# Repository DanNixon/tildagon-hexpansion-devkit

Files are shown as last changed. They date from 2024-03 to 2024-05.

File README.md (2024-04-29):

# Tildagon Hexpansion dev kit

A basic, quick and dirty development kit for hexpansions for the [Tildagon](https://tildagon.badge.emfcamp.org/) badge.

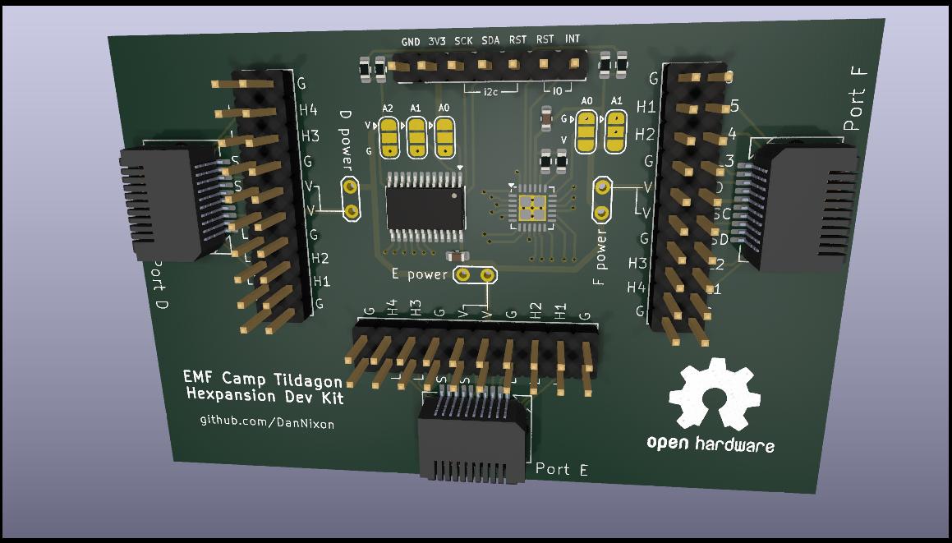
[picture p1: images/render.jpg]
KiCad render of dev kit PCB Dev kit PCB render


Accurately replicates i2c and low speed IO/LED drivers of ports D, E and F from the actual badge, with breakouts for the entire expansion port.
i2c is as per the actual badge, with the AW9523B connected to port 7 of the TCA9548A.
Default address configuration of both the AW9523B and TCA9548A match what is used on the badge (so you should not have to adjust the solder jumpers).

Paired with your ESP32-S3 dev board of choice, this should allow you to develop something more than "shape with LED" hexpansions prior to EMF 2024.

## Pinouts

"Pin" refers to the index used on the Tildagon design files.
"Letter" refers to the letter assigned to the pins in the Hexpansion example.
Why the two different pin identification schemes exist is a mystery to me...

### Low Speed

| Pin | Letter | Port D | Port E | Port F |
|-----|---|---|---|---|
| 1 | A | 1.0 | 0.2 | 0.7 |
| 2 | B | 1.1 | 0.3 | 1.4 |
| 3 | C | 1.2 | 0.4 | 1.5 |
| 4 | D | 1.3 | 0.5 | 1.6 |
| 5 | E | 0.0 | 0.6 | 1.7 |

### High Speed

| Pin | Letter |
|-----|---|
| 1 | F |
| 2 | G |
| 3 | H |
| 4 | I |

### i2c

| Bus | Port |
|-----|---|
| 4 | D |
| 5 | E |
| 6 | F |
| 7 | sys  |

## See also

- [badge-2024-hardware](https://github.com/emfcamp/badge-2024-hardware)
- [TCA9548A datasheet](https://www.ti.com/lit/ds/symlink/tca9548a.pdf)
- [AW9523B datasheet](https://cdn-shop.adafruit.com/product-files/4886/AW9523+English+Datasheet.pdf)
- [Hexpansion developer guide](https://tildagon.badge.emfcamp.org/technical-reference/hexpansions/)

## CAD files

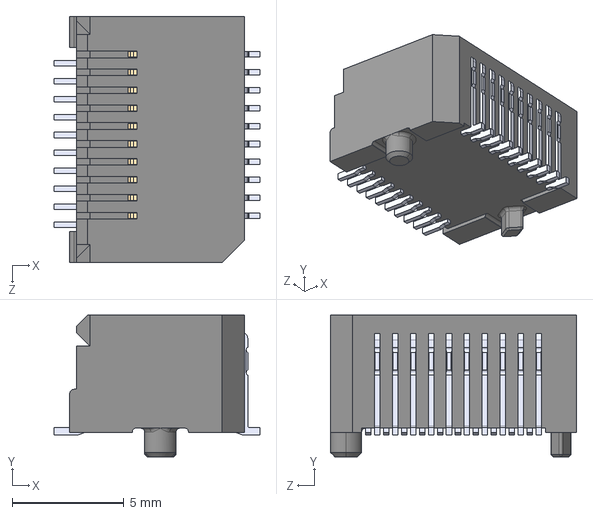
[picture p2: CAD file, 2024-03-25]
pcb/3d/UE75-A20-6000T.step
9.20 x 6.33 x 11.0 mm

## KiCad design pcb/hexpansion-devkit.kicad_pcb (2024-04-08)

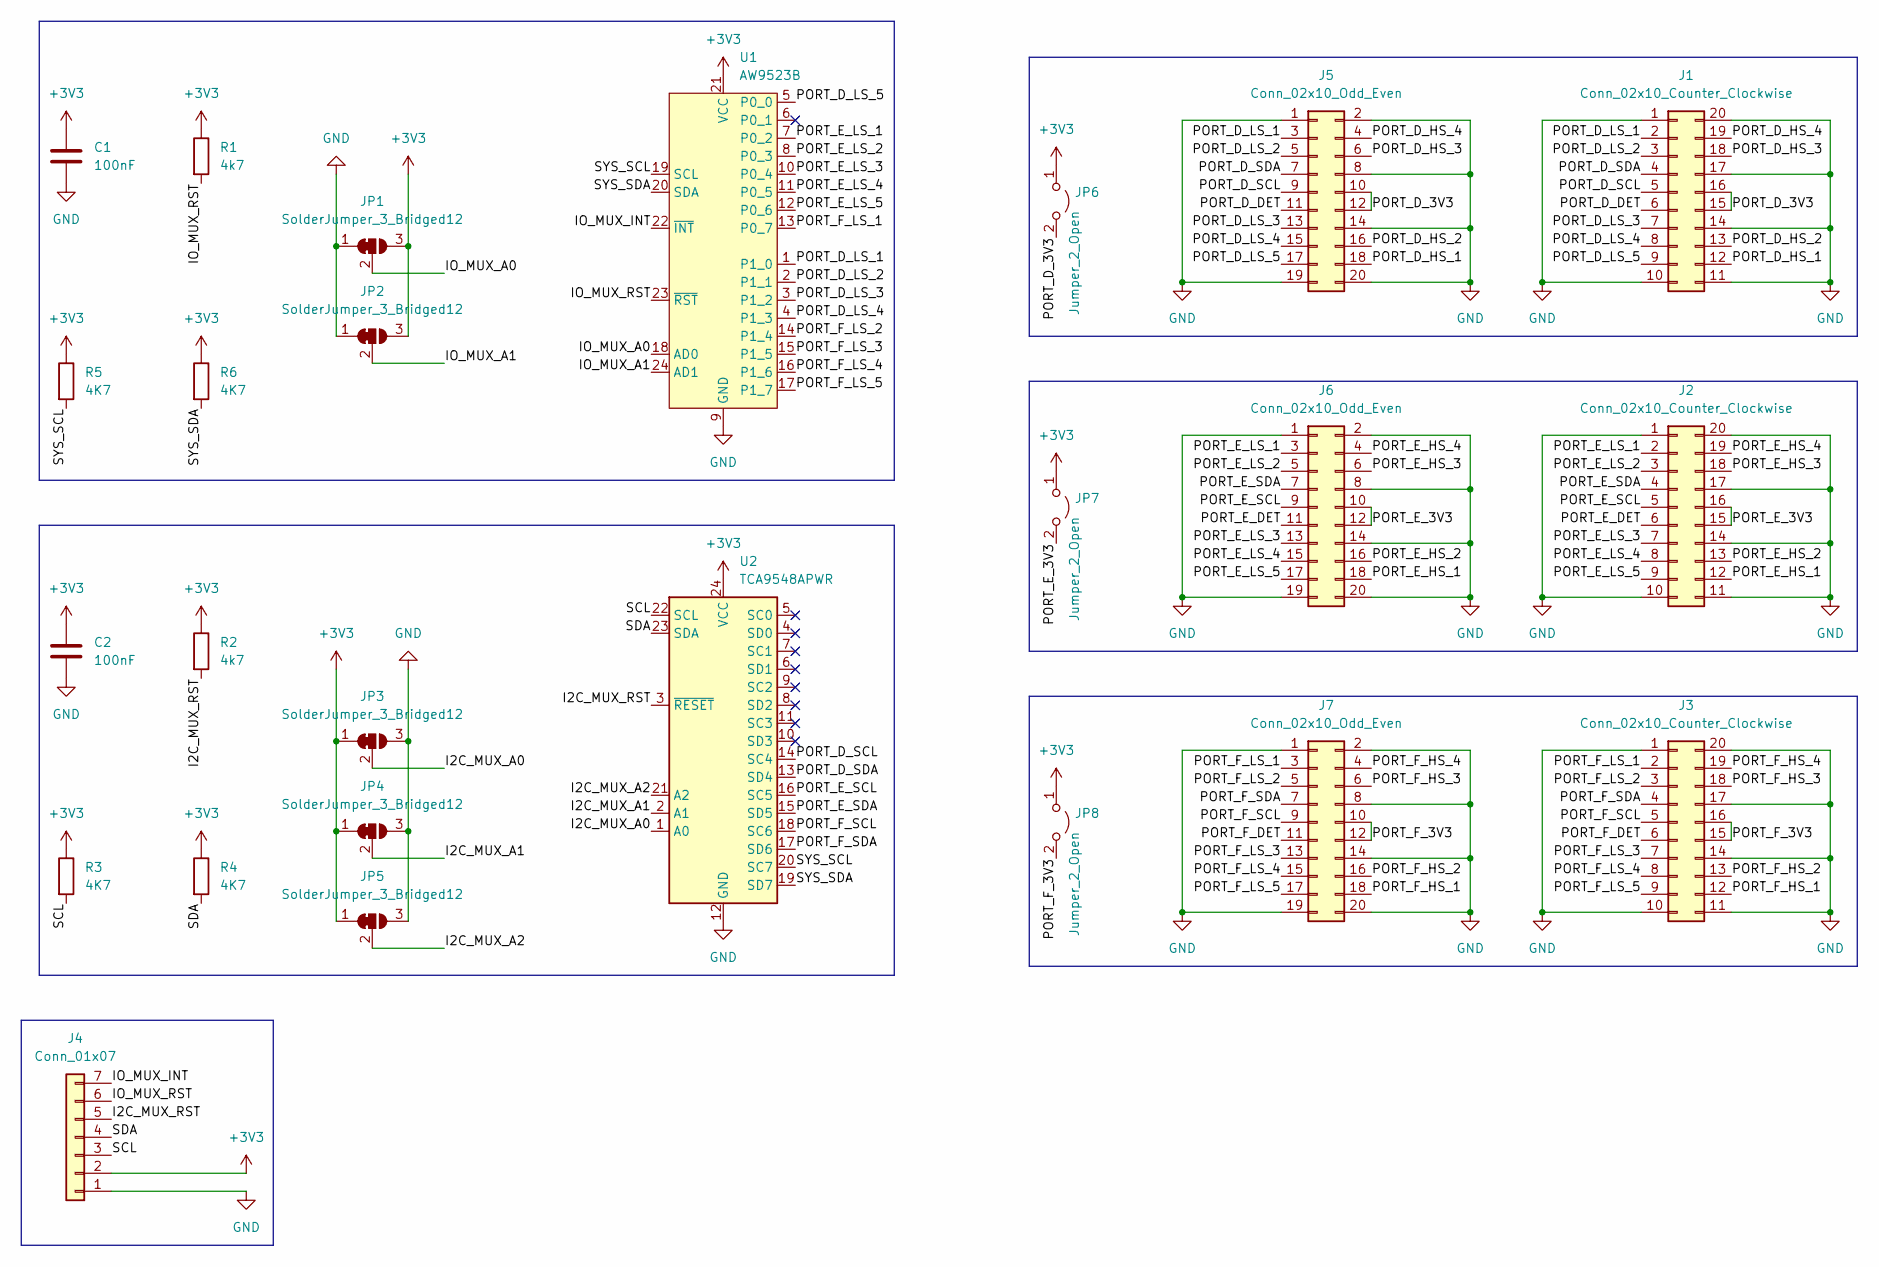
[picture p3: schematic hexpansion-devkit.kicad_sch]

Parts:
C1, C2: 100nF; C_0603_1608Metric; LCSC C497032
J1, J2, J3: Conn_02x10_Counter_Clockwise; SFP; LCSC C2897291
J4: Conn_01x07; PinHeader_1x07_P2.54mm_Vertical
J5, J6, J7: Conn_02x10_Odd_Even; PinHeader_2x10_P2.54mm_Vertical
JP1, JP2, JP3, JP4, JP5: SolderJumper_3_Bridged12; SolderJumper-3_P1.3mm_Bridged12_RoundedPad1.0x1.5mm
JP6, JP7, JP8: Jumper_2_Open; TestPoint_2Pads_Pitch2.54mm_Drill0.8mm
R1, R2: 4k7; R_0603_1608Metric; LCSC C217361
R3, R4, R5, R6: 4K7; R_0603_1608Metric; LCSC C217361
U1: AW9523B; QFN-24-1EP_4x4mm_P0.5mm_EP2.7x2.6mm; LCSC C148077
U2: TCA9548APWR; TSSOP-24_4.4x7.8mm_P0.65mm; LCSC C130026

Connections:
+3V3: C1.1, C2.1, J4.2, JP1.3 (B), JP2.3 (B), JP3.1 (A), JP4.1 (A), JP5.1 (A), JP6.1 (A), JP7.1 (A), JP8.1 (A), R1.1, R2.1, R3.1, R4.1, R5.1, R6.1, U1.21 (VCC), U2.24 (VCC)
/I2C_MUX_A0: JP3.2 (C), U2.1 (A0)
/I2C_MUX_A1: JP4.2 (C), U2.2 (A1)
/I2C_MUX_A2: JP5.2 (C), U2.21 (A2)
/I2C_MUX_RST: J4.5, R2.2, U2.3 (~RESET)
/IO_MUX_A0: JP1.2 (C), U1.18 (AD0)
/IO_MUX_A1: JP2.2 (C), U1.24 (AD1)
/IO_MUX_INT: J4.7, U1.22 (~INT)
/IO_MUX_RST: J4.6, R1.2, U1.23 (~RST)
/PORT_D_3V3: J1.15, J1.16, J5.10, J5.12, JP6.2 (B)
/PORT_D_DET: J1.6, J5.11
/PORT_D_HS_1: J1.12, J5.18
/PORT_D_HS_2: J1.13, J5.16
/PORT_D_HS_3: J1.18, J5.6
/PORT_D_HS_4: J1.19, J5.4
/PORT_D_LS_1: J1.2, J5.3, U1.1 (P1_0)
/PORT_D_LS_2: J1.3, J5.5, U1.2 (P1_1)
/PORT_D_LS_3: J1.7, J5.13, U1.3 (P1_2)
/PORT_D_LS_4: J1.8, J5.15, U1.4 (P1_3)
/PORT_D_LS_5: J1.9, J5.17, U1.5 (P0_0)
/PORT_D_SCL: J1.5, J5.9, U2.14 (SC4)
/PORT_D_SDA: J1.4, J5.7, U2.13 (SD4)
/PORT_E_3V3: J2.15, J2.16, J6.10, J6.12, JP7.2 (B)
/PORT_E_DET: J2.6, J6.11
/PORT_E_HS_1: J2.12, J6.18
/PORT_E_HS_2: J2.13, J6.16
/PORT_E_HS_3: J2.18, J6.6
/PORT_E_HS_4: J2.19, J6.4
/PORT_E_LS_1: J2.2, J6.3, U1.7 (P0_2)
/PORT_E_LS_2: J2.3, J6.5, U1.8 (P0_3)
/PORT_E_LS_3: J2.7, J6.13, U1.10 (P0_4)
/PORT_E_LS_4: J2.8, J6.15, U1.11 (P0_5)
/PORT_E_LS_5: J2.9, J6.17, U1.12 (P0_6)
/PORT_E_SCL: J2.5, J6.9, U2.16 (SC5)
/PORT_E_SDA: J2.4, J6.7, U2.15 (SD5)
/PORT_F_3V3: J3.15, J3.16, J7.10, J7.12, JP8.2 (B)
/PORT_F_DET: J3.6, J7.11
/PORT_F_HS_1: J3.12, J7.18
/PORT_F_HS_2: J3.13, J7.16
/PORT_F_HS_3: J3.18, J7.6
/PORT_F_HS_4: J3.19, J7.4
/PORT_F_LS_1: J3.2, J7.3, U1.13 (P0_7)
/PORT_F_LS_2: J3.3, J7.5, U1.14 (P1_4)
/PORT_F_LS_3: J3.7, J7.13, U1.15 (P1_5)
/PORT_F_LS_4: J3.8, J7.15, U1.16 (P1_6)
/PORT_F_LS_5: J3.9, J7.17, U1.17 (P1_7)
/PORT_F_SCL: J3.5, J7.9, U2.18 (SC6)
/PORT_F_SDA: J3.4, J7.7, U2.17 (SD6)
/SCL: J4.3, R3.2, U2.22 (SCL)
/SDA: J4.4, R4.2, U2.23 (SDA)
/SYS_SCL: R5.2, U1.19 (SCL), U2.20 (SC7)
/SYS_SDA: R6.2, U1.20 (SDA), U2.19 (SD7)
GND: C1.2, C2.2, J1.1, J1.10, J1.11, J1.14, J1.17, J1.20, J2.1, J2.10, J2.11, J2.14, J2.17, J2.20, J3.1, J3.10, J3.11, J3.14, J3.17, J3.20, J4.1, J5.1, J5.2, J5.8, J5.14, J5.19, J5.20, J6.1, J6.2, J6.8, J6.14, J6.19, J6.20, J7.1, J7.2, J7.8, J7.14, J7.19, J7.20, JP1.1 (A), JP2.1 (A), JP3.3 (B), JP4.3 (B), JP5.3 (B), U1.9 (GND), U1.25 (GND), U2.12 (GND)

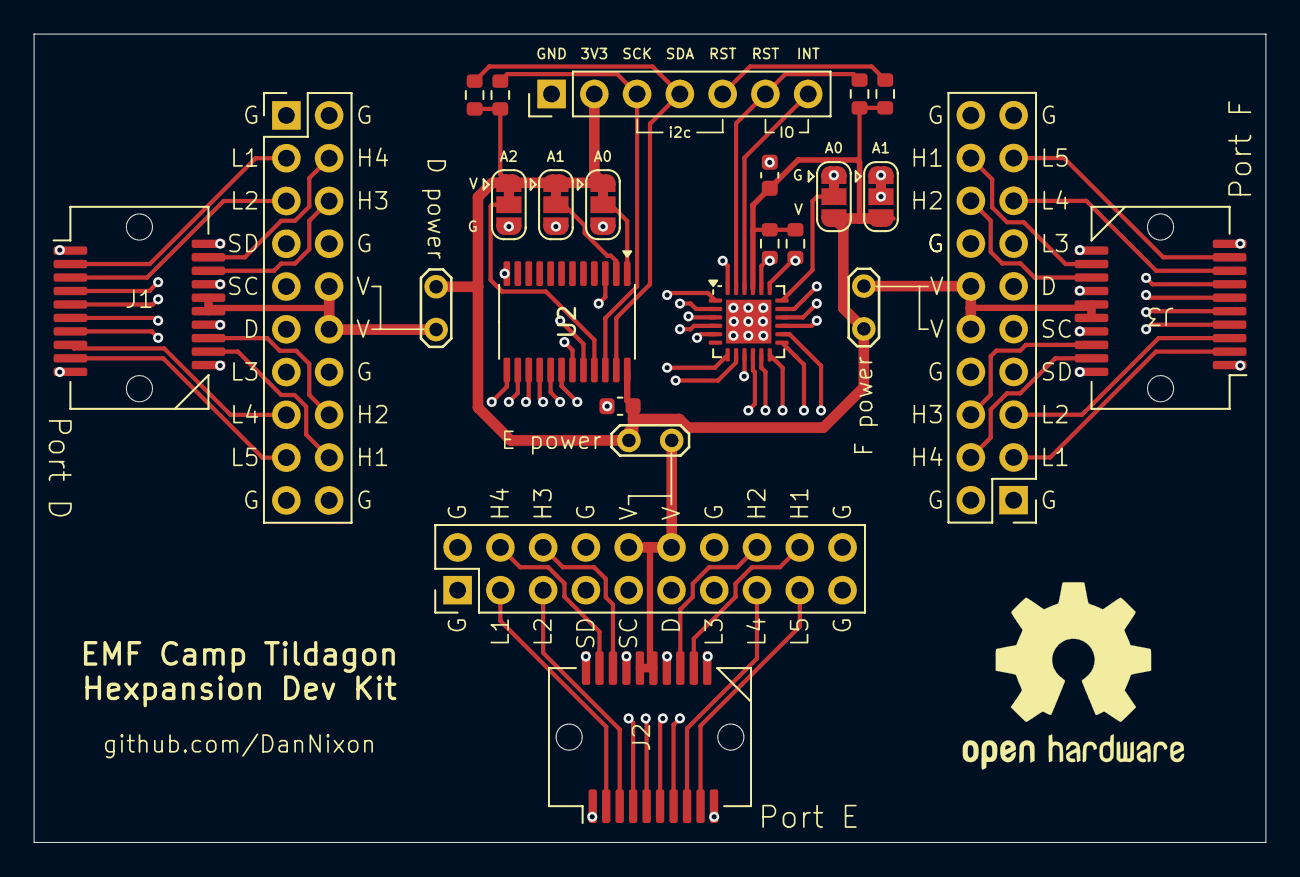
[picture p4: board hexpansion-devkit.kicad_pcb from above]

Board: 4 copper layers, 73.2 x 48.0 mm, 25 parts (0 on the bottom side), 53 nets.

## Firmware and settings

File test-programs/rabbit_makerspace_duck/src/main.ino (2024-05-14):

#include "Wire.h"
#include <Adafruit_AW9523.h>

static constexpr auto TCAADDR = 0x77;

void tcaselect(uint8_t i) {
  if (i > 7)
    return;

  Wire.beginTransmission(TCAADDR);
  Wire.write(1 << i);
  Wire.endTransmission();
}

void select_sys_i2c() { tcaselect(7); }

void select_port_d_i2c() { tcaselect(4); }

void select_port_e_i2c() { tcaselect(5); }

void select_port_f_i2c() { tcaselect(6); }

Adafruit_AW9523 badge_io;

Adafruit_AW9523 ms_hexpansion_io_1;
Adafruit_AW9523 ms_hexpansion_io_2;

uint8_t rabbit_red_pin = 0;    // Port D, LS E
uint8_t rabbit_green_pin = 10; // Port D, LS C
uint8_t rabbit_blue_pin = 11;  // Port D, LS D

uint8_t duck_red_pin = 15;   // Port F, LS E
uint8_t duck_green_pin = 14; // Port F, LS D
uint8_t duck_blue_pin = 13;  // Port F, LS C

void setup() {
  Serial.begin(115200);
  Serial.println("Adafruit AW9523 GPIO Expander test!");

  Wire.setPins(26, 27);
  Wire.begin();

  select_sys_i2c();

  Serial.print("Badge AW9523 good? : ");
  Serial.println(badge_io.begin(0x58));

  badge_io.pinMode(rabbit_red_pin, AW9523_LED_MODE);
  badge_io.pinMode(rabbit_green_pin, AW9523_LED_MODE);
  badge_io.pinMode(rabbit_blue_pin, AW9523_LED_MODE);

  badge_io.pinMode(duck_red_pin, AW9523_LED_MODE);
  badge_io.pinMode(duck_green_pin, AW9523_LED_MODE);
  badge_io.pinMode(duck_blue_pin, AW9523_LED_MODE);

  select_port_e_i2c();

  Serial.print("MS Hexpansion AW9523 1 good? : ");
  Serial.println(ms_hexpansion_io_1.begin(0x5A));

  Serial.print("MS Hexpansion AW9523 2 good? : ");
  Serial.println(ms_hexpansion_io_2.begin(0x5B));

  for (int i = 0; i < 16; i++) {
    ms_hexpansion_io_1.pinMode(i, AW9523_LED_MODE);
    ms_hexpansion_io_2.pinMode(i, AW9523_LED_MODE);
  }

  select_sys_i2c();

  badge_io.analogWrite(rabbit_red_pin, 4);
  badge_io.analogWrite(duck_blue_pin, 4);

  select_port_e_i2c();
}

void loop() {
  set_m_intensity(0);
  m_breathe_effect();

  set_m_intensity(0);
  m_scroll_effect();
}

// clang-format off
std::array<std::tuple<int, int>, 29> segments = {
    std::make_tuple(0, 7),
    std::make_tuple(0, 12),
    std::make_tuple(0, 13),
    std::make_tuple(0, 14),
    std::make_tuple(0, 15),
    std::make_tuple(0, 6),
    std::make_tuple(0, 5),
    std::make_tuple(0, 4),
    std::make_tuple(0, 3),
    std::make_tuple(0, 2),
    std::make_tuple(0, 1),
    std::make_tuple(0, 0),
    std::make_tuple(0, 11),
    std::make_tuple(0, 10),
    std::make_tuple(0, 9),
    std::make_tuple(0, 8),
    std::make_tuple(1, 7),
    std::make_tuple(1, 12),
    std::make_tuple(1, 6),
    std::make_tuple(1, 5),
    std::make_tuple(1, 4),
    std::make_tuple(1, 3),
    std::make_tuple(1, 2),
    std::make_tuple(1, 1),
    std::make_tuple(1, 0),
    std::make_tuple(1, 8),
    std::make_tuple(1, 9),
    std::make_tuple(1, 10),
    std::make_tuple(1, 11),
};
// clang-format on

void m_scroll_effect() {
  for (const auto &segment : segments) {
    auto expander = std::get<0>(segment);
    auto pin = std::get<1>(segment);

    set_m_intensity(0);
    if (expander == 0) {
      ms_hexpansion_io_1.analogWrite(pin, 12);
    } else if (expander == 1) {
      ms_hexpansion_io_2.analogWrite(pin, 12);
    }

    Serial.println("-");
    delay(50);
  }
}

void m_breathe_effect() {
  for (int i = 0; i < 24; i++) {
    set_m_intensity(i);
    delay(10);
  }
  for (int i = 22; i > 0; i--) {
    set_m_intensity(i);
    delay(10);
  }
}

void set_m_intensity(int intensity) {
  for (int i = 0; i < 16; i++) {
    ms_hexpansion_io_1.analogWrite(i, intensity);
    ms_hexpansion_io_2.analogWrite(i, intensity);
  }
}

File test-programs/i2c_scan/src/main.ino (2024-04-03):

#include "Wire.h"

static constexpr auto TCAADDR = 0x77;

void tcaselect(uint8_t i) {
  if (i > 7)
    return;

  Wire.beginTransmission(TCAADDR);
  Wire.write(1 << i);
  Wire.endTransmission();
}

void setup() {
  Serial.begin(115200);
  Serial.println("\nTCAScanner ready!");

  Wire.setPins(26, 27);
  Wire.begin();

  for (uint8_t t = 0; t < 8; t++) {
    tcaselect(t);
    Serial.print("TCA Port #");
    Serial.println(t);

    for (uint8_t addr = 0; addr <= 127; addr++) {
      if (addr == TCAADDR)
        continue;

      Wire.beginTransmission(addr);
      if (!Wire.endTransmission()) {
        Serial.print("Found I2C 0x");
        Serial.println(addr, HEX);
      }
    }
  }

  Serial.println("\ndone");
}

void loop() {}

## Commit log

2024-03-25 Revision 1
    [UE75-A20-6000T.step, hexpansion-devkit.kicad_pcb, hexpansion-devkit.kicad_sch]
2024-04-03 Revision 2
    [hexpansion-devkit.kicad_pcb, hexpansion-devkit.kicad_sch]
2024-04-03 Move PCB files to subdir
    [UE75-A20-6000T.step, hexpansion-devkit.kicad_pcb, hexpansion-devkit.kicad_sch]
2024-04-08 Tidy PCB silkscreen, add new render
    [hexpansion-devkit.kicad_pcb]
